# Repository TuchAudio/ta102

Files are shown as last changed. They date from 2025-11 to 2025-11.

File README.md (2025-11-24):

# TuchAudio 102
Discrete, _tube-like_ phono preamp.

_**NO LONGER RECOMMENDED, use [TuchAudio 103](../../../ta103) instead.**_

## Purpose
Discrete, non-op-amp classic design phono preamp, made as simple as possible.

## Design quirks
_After_ the original PCB was ordered, overload margin was deemed insufficient; thus a **hack** was made, essentialy _swapping the two first stages_ of the preamp.

DIN and RCA jacks are provided for signal input. Since the _native_ input impedance is around **110 kΩ**, space for suitable load (`Rx` and `Cx`) is provided for perfect adaptation; but for added flexibility, it is possible to use the free input for a suitable RC combo in parallel, to match the appropriate cartridge load.

Originally intended to be connected thru the [501 Input Selector board](../../../ta501), both output pins and power input are at compatible locations within each board. An aditional RCA **output** jack can be installed in order to use the circuit as a _stand-alone preamp_.

### Stability

As any other amplifier with _asymmetrical power supply_, the PSRR is very poor, thus a **well filtered, stable** power supply is essential. Increasing (within reason) `R114/R214` may help a bit.

This circuit has proved to be _quite sensitive to capacitor quality_, especially at `C102/C103/C202/C203` positions which, in some cases, may lead to **instability**. For all these reasons we recommend using the [103 Phono Preamp](../../../ta103) instead, which is a direct replacement in the very **same form factor**.

### Suggested mods

#### Standalone mode

Despite being designed around a 12 Volt power supply, this can be run from a single **9 Volt battery**, with minor changes and similar performance.

- `R114/R214`: use **120 Ω** instead of 180.
- `R111/R211`: use **2.7 kΩ** instead of 3K3.
-  ...

#### IEC1976/Neumann ammendments

The stated values are designed around these _ammendments_ to the **RIAA curve**; but since they're currently _deprecated_, you may get **improved bass response** by turning back to RIAA correction:

- `C105/C205`: do not mount (Neumann ammendment)
- `C107/C207`: use **220 nF** or more instead of 100 nF (which made a _-3 dB point at 20 Hz_ **over 108 kΩ** of the _501 board_ input)

## Specs

- **Power supply:** 9-12 V, asymmetrical, max. 6 mA
- **Input connectors:** 2x RCA plus DIN (in parallel)
- **Gain at 1 kHz:** 50x (+34 dB)
- **Input sensitivity:** 3.6 mV (for 180 mV output)
- **Input impedance:** 108 kΩ; adjusted by `Rx/Cx`, either internal or external.
- **Output level and impedance:** 180 mV / 3.3 KΩ
- **Overload margin:** at least +15 dB
- **Signal-to-noise ratio:** TBD
- **Frequency response:** 32 Hz - 20 kHz _(+1.5/-2 dB deviation from RIAA; -3 dB beyond audible range)_
- **Distortion:** (most notably from **2nd harmonic**, which may resemble **tube sound**)

| Harmonic | nominal output | +15 dB overload |
| --- | --- | --- |
| 2nd | 0.55 % | **8 %** |
| 3rd | 0.16 % | 0.59 % |
| 4th | 0.08 % | 0.28 %  |
| 5th | negligible | 0.08 % |

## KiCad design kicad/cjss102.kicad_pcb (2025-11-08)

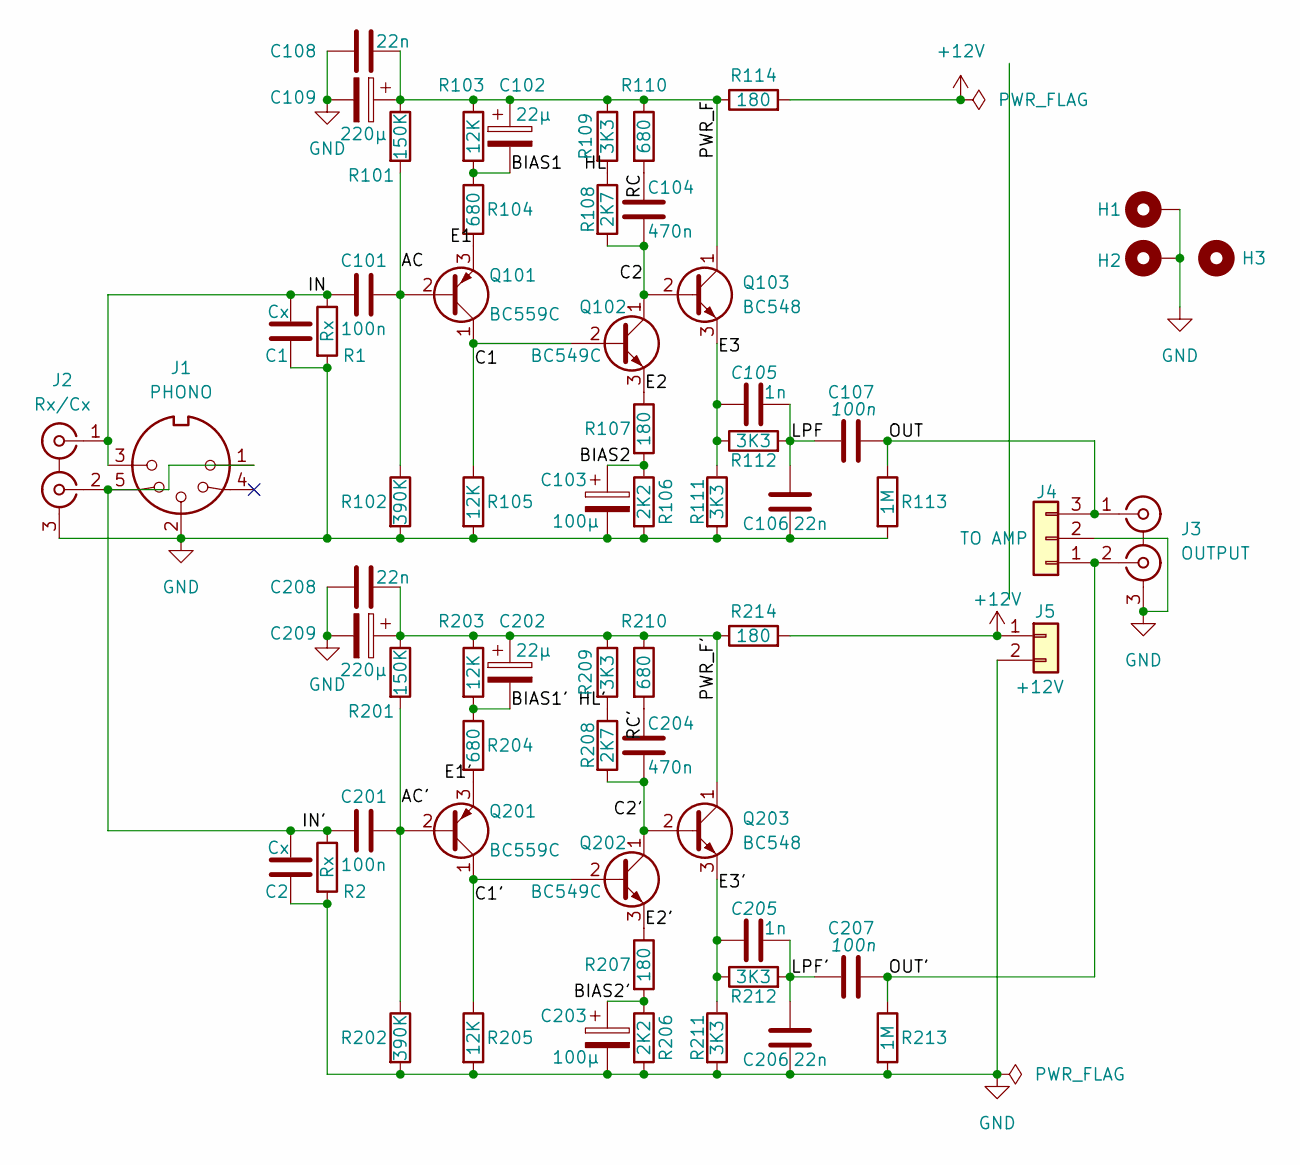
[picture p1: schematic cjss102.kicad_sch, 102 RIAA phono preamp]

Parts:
C1, C2: Cx; PinSocket_1x02_P2.54mm_Vertical
C101, C107, C201, C207: 100n; C_Rect_L7.2mm_W2.5mm_P5.00mm_FKS2_FKP2_MKS2_MKP2
C102, C202: 22µ; CP_Radial_D4.0mm_P1.50mm
C103, C203: 100µ; CP_Radial_D4.0mm_P1.50mm
C104, C204: 470n; C_Rect_L7.2mm_W3.0mm_P5.00mm_FKS2_FKP2_MKS2_MKP2
C105, C205: 1n; C_Rect_L7.2mm_W2.5mm_P5.00mm_FKS2_FKP2_MKS2_MKP2
C106, C206: 22n; C_Rect_L7.2mm_W2.5mm_P5.00mm_FKS2_FKP2_MKS2_MKP2
C108, C208: 22n; C_Disc_D6.0mm_W2.5mm_P5.00mm
C109, C209: 220µ; CP_Radial_D6.3mm_P2.50mm
H1, H2: MountingHole_Pad; MountingHole_3.2mm_M3_DIN965_Pad
H3: MountingHole; MountingHole_3.2mm_M3
J1: PHONO; DIN 5-180deg
J2: Rx/Cx; 2xRCA_vertical
J3: OUTPUT; 2xRCA_vertical
J4: TO AMP; PinHeader_1x03_P2.54mm_Horizontal
J5: +12V; PinHeader_1x02_P2.54mm_Horizontal
Q101, Q201: BC559C; TO-92_Inline
Q102, Q202: BC549C; TO-92_Inline
Q103, Q203: BC548; TO-92_Inline
R1, R2: Rx; PinSocket_1x02_P2.54mm_Vertical
R101, R201: 150K; R_Axial_DIN0207_L6.3mm_D2.5mm_P10.16mm_Horizontal
R102, R202: 390K; R_Axial_DIN0207_L6.3mm_D2.5mm_P10.16mm_Horizontal
R103, R105, R203, R205: 12K; R_Axial_DIN0207_L6.3mm_D2.5mm_P10.16mm_Horizontal
R104, R110, R204, R210: 680; R_Axial_DIN0207_L6.3mm_D2.5mm_P10.16mm_Horizontal
R106, R206: 2K2; R_Axial_DIN0207_L6.3mm_D2.5mm_P10.16mm_Horizontal
R107, R114, R207, R214: 180; R_Axial_DIN0207_L6.3mm_D2.5mm_P10.16mm_Horizontal
R108, R208: 2K7; R_Axial_DIN0207_L6.3mm_D2.5mm_P10.16mm_Horizontal
R109, R111, R112, R209, R211, R212: 3K3; R_Axial_DIN0207_L6.3mm_D2.5mm_P10.16mm_Horizontal
R113, R213: 1M; R_Axial_DIN0207_L6.3mm_D2.5mm_P10.16mm_Horizontal

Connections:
+12V: J5.1, R114.2, R214.2
/AC: C101.2, Q101.2 (B), R101.2, R102.1
/AC': C201.2, Q201.2 (B), R201.2, R202.1
/BIAS1: C102.2, R103.2, R104.1
/BIAS1': C202.2, R203.2, R204.1
/BIAS2: C103.1, R106.1, R107.2
/BIAS2': C203.1, R206.1, R207.2
/C1: Q101.1 (C), Q102.2 (B), R105.1
/C1': Q201.1 (C), Q202.2 (B), R205.1
/C2: C104.2, Q102.1 (C), Q103.2 (B), R108.2
/C2': C204.2, Q202.1 (C), Q203.2 (B), R208.2
/E1: Q101.3 (E), R104.2
/E1': Q201.3 (E), R204.2
/E2: Q102.3 (E), R107.1
/E2': Q202.3 (E), R207.1
/E3: C105.1, Q103.3 (E), R111.1, R112.1
/E3': C205.1, Q203.3 (E), R211.1, R212.1
/HL: R108.1, R109.2
/HL': R208.1, R209.2
/IN: C1.1, C101.1, J1.3, J2.1 (IN1), R1.1
/IN': C2.1, C201.1, J1.1, J1.5, J2.2 (IN2), R2.1
/LPF: C105.2, C106.1, C107.1, R112.2
/LPF': C205.2, C206.1, C207.1, R212.2
/OUT: C107.2, J3.1 (IN1), J4.3, R113.1
/OUT': C207.2, J3.2 (IN2), J4.1, R213.1
/PWR_F: C102.1, C108.2, C109.1, Q103.1 (C), R101.1, R103.1, R109.1, R110.1, R114.1
/PWR_F': C202.1, C208.2, C209.1, Q203.1 (C), R201.1, R203.1, R209.1, R210.1, R214.1
/RC: C104.1, R110.2
/RC': C204.1, R210.2
GND: C1.2, C2.2, C103.2, C106.2, C108.1, C109.2, C203.2, C206.2, C208.1, C209.2, H1.1, H2.1, J1.2, J2.3 (EXT), J3.3 (EXT), J4.2, J5.2, R1.2, R2.2, R102.2, R105.2, R106.2, R111.2, R113.2, R202.2, R205.2, R206.2, R211.2, R213.2

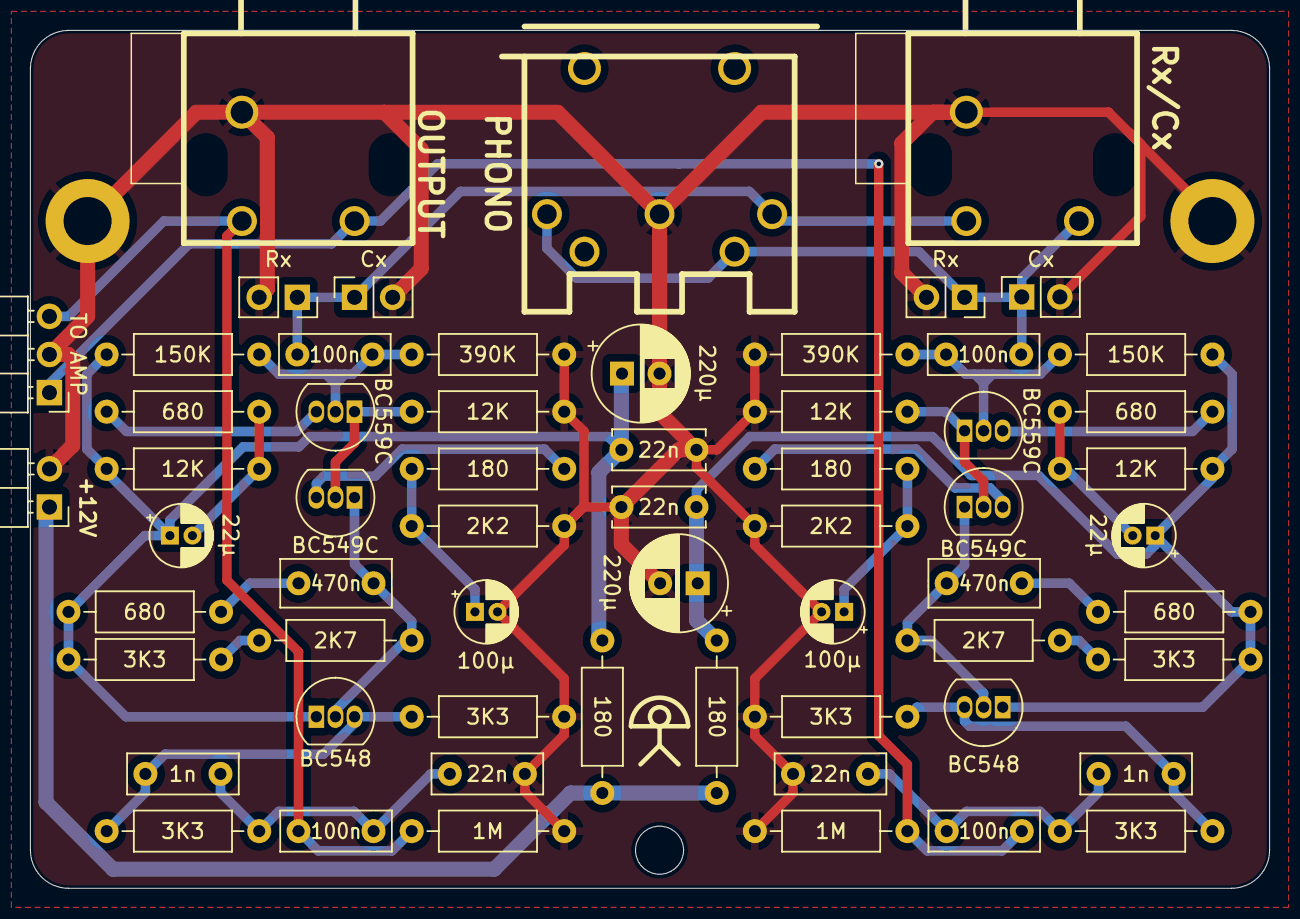
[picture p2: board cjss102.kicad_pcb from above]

Board: 2 copper layers, 82.5 x 57.1 mm, 64 parts (0 on the bottom side), 30 nets.
